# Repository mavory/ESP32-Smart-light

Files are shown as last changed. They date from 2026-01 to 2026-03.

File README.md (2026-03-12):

# ESP32 Smart Light

A system that is powered by ESP32 and controls 2 LED strips and a neopixel ring using clapping and the web!



## Why did I do this?

I wanted to create a system that could be controlled using my new Big sound module, so I started thinking and came up with this interesting idea!

## Features

- Web interface
- It has a buzzer and an RGB LED for notification
- You can clap to turn the lights on/off
- You have a neopixel ring that you can set up to 10+ mods on

## Scripts

In total, the script has about 650 lines, but the website, functions,... It´s only in this script. So just upload it via Arduino IDE to ESP32 and everything should work!!

### Home page:


## How it works?

- **Clap control:** 1x clap toggles the LED strip!! 2x claps toggle the ring and 3x claps change the ring mode
- **Physical button:** 1x click toggles the LED strip, 2x click changes brightness (strip), 3x click swaps ring modes. Long press turns the system On/Off
- **Web UI:** Change 12 ring modes (Matrix, Fire, Rainbow, etc.), 3 strip effects, and brightness
- **Status LED:** Shows WiFi status and gives color feedback (Green/Red/Blue) when you change settings
- **Auto Demo:** Randomly cycles through all ring effects every 10 seconds....

### Libraries:

```
- Adafruit_NeoPixel.h
- OneButton.h
- WiFi.h
- WebServer.h
- Preferences.h
```

## 3D models

https://www.tinkercad.com/things/eFkPVTd0Ne4-lamp?sharecode=UNrX2Xw5hONzTC9dqX5OnXKPG04cPSQhPtq6QzThrkk

Here is a view of the top and bottom of the case:

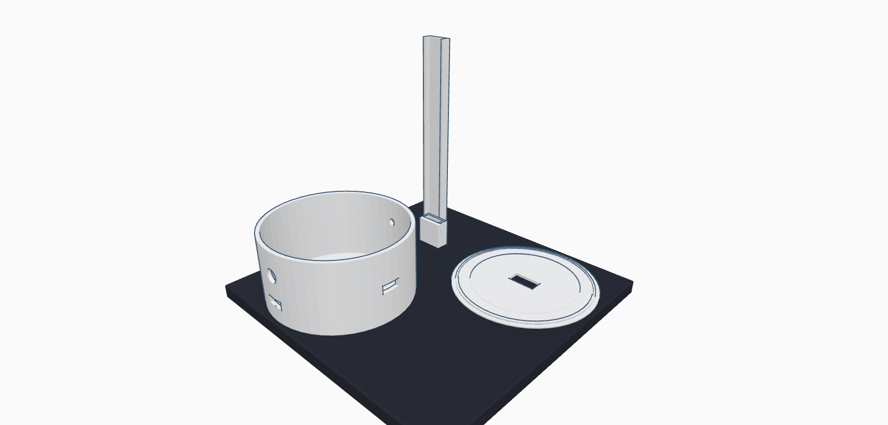
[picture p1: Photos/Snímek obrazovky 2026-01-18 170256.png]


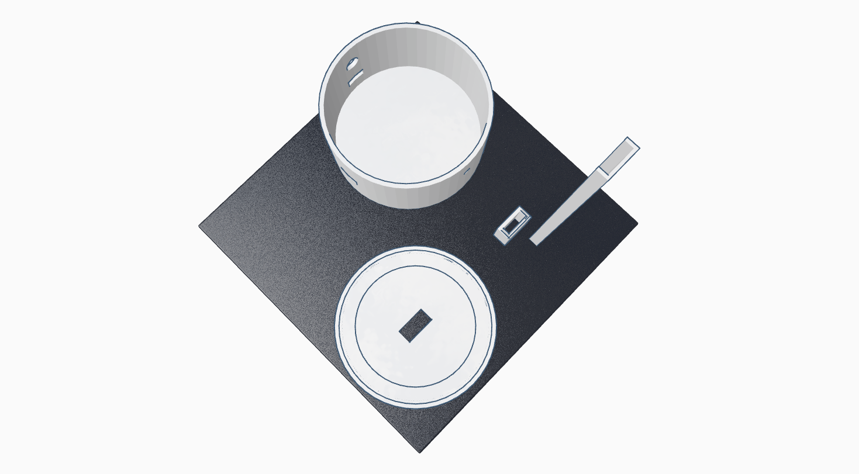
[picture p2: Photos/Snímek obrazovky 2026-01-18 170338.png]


## Wiring Diagram



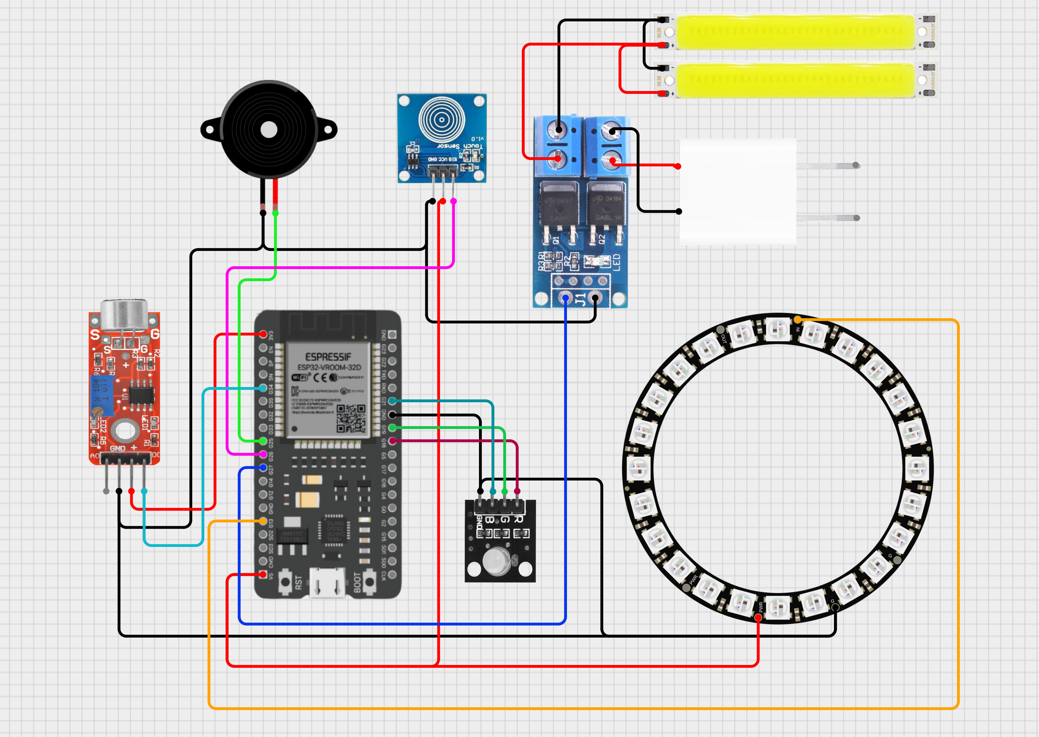
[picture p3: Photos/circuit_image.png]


## There is the final video of how it works!

_Here is a youtube video where you can see how it works:_ [Link](https://youtu.be/ElwXBvMZj_E)

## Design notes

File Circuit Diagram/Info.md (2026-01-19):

Documentation for the Smart light Control System!!

## Wiring

### LED Strip (MOSFET)
- Gate: GPIO 27
- VCC: 5V (External)
- GND: GND

### NeoPixel Ring (24 LEDs)
- Data In: GPIO 13
- VCC: 5V
- GND: GND

### Sound Sensor (Microphone)
- Digital Out: GPIO 34
- VCC: 3.3V/5V
- GND: GND

### Main Button
- Pin: GPIO 26
- GND: GND

### Buzzer
- Pin: GPIO 25
- GND: GND

### RGB Status LED (Common Cathode)
- Red: GPIO 18
- Green: GPIO 19
- Blue: GPIO 21
- Cathode: GND

---

## Technical Notes
- **Power:** The LED strip requires an external 5V power supply.

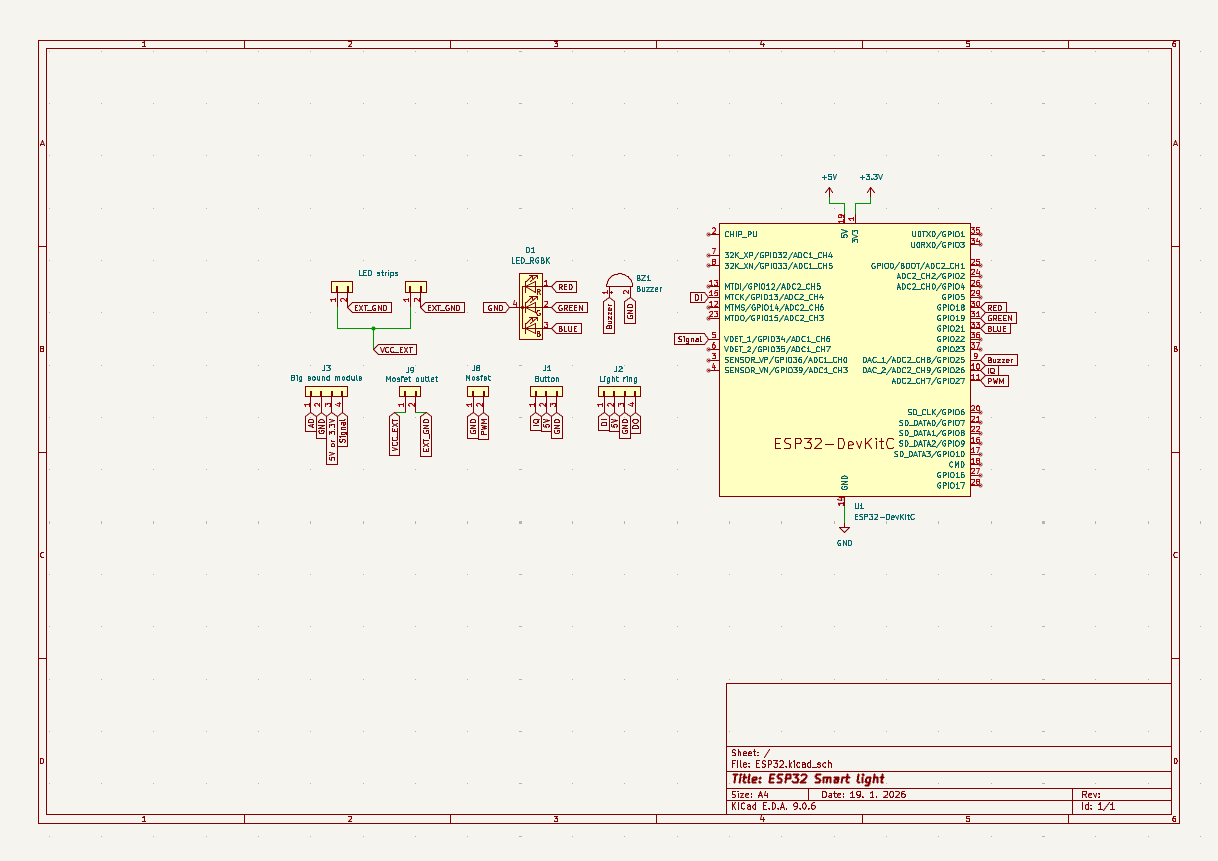
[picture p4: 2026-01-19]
Photos/Snímek obrazovky 2026-01-19 185331.png

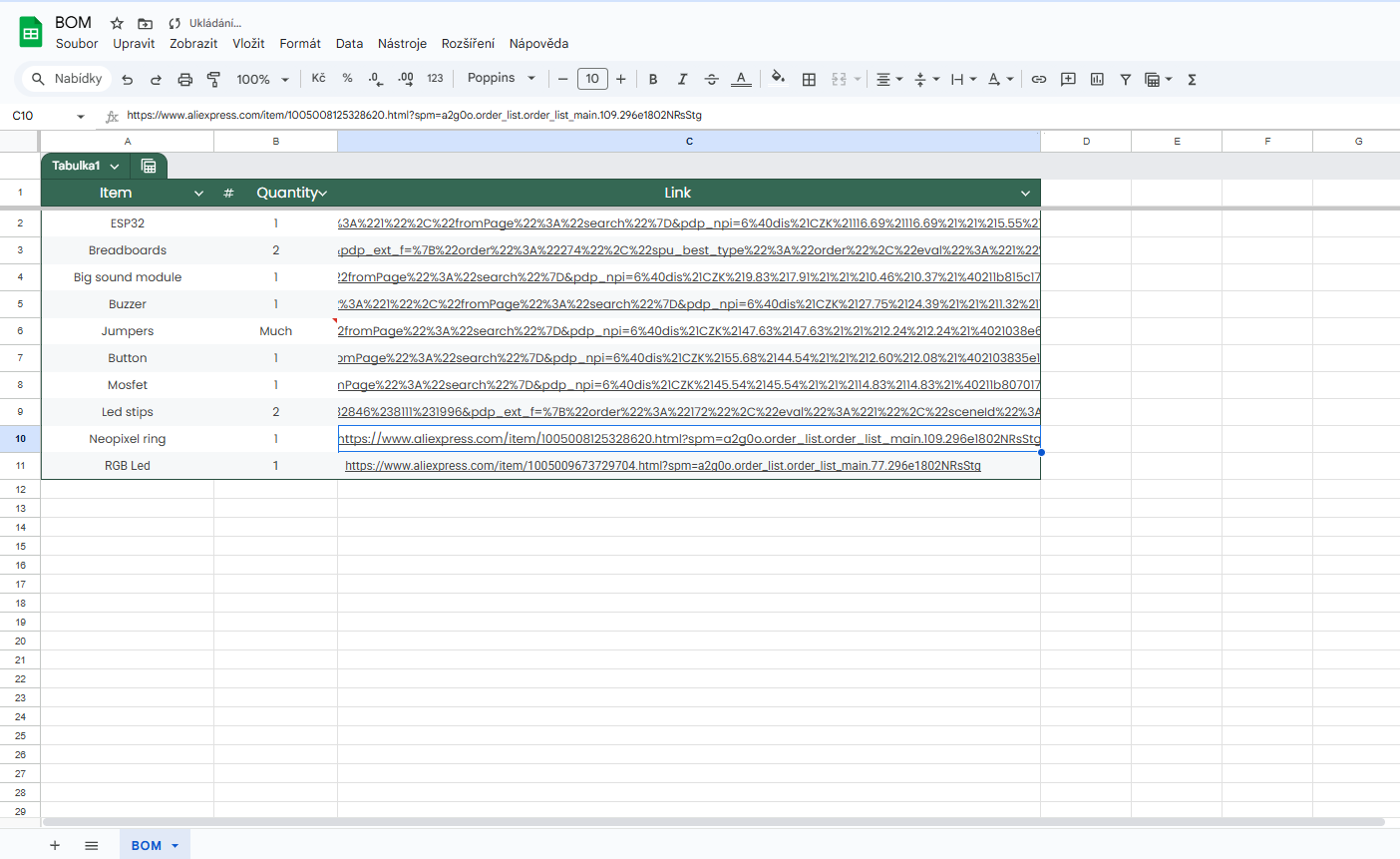
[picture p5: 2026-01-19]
Photos/Snímek obrazovky 2026-01-19 191405.png

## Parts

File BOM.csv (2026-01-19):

Item | Quantity | Link
ESP32 | 1 | https://www.aliexpress.com/item/1005009694232832.html?curPageLogUid=bPYYmnweQOZ8
Breadboards | 2 | https://www.aliexpress.com/item/1005007493250982.html?scm_id=1007.40050.354490.0&scm-url=1007.40050.354490.0
Big sound module | 1 | https://www.aliexpress.com/item/1005009123651703.html?curPageLogUid=UiuB2XQiP4lX
Buzzer | 1 | https://www.aliexpress.com/item/1005006260328559.html?curPageLogUid=u9zf8d5xh8uM
Jumpers | Much | https://www.aliexpress.com/item/1005002611994443.html?curPageLogUid=fx2zB0EGcu5H
Button | 1 | https://www.aliexpress.com/item/1005007197228321.html?curPageLogUid=niWf4yREvIVl
Mosfet | 1 | https://www.aliexpress.com/item/1005008593846004.html?curPageLogUid=lKbC2NYKhWH8
Led stips | 2 | https://www.aliexpress.com/item/4000121451290.html?scm_id=1007.40050.354490.0&scm-url=1007.40050.354490.0
Neopixel ring | 1 | https://www.aliexpress.com/item/1005008125328620.html
RGB Led | 1 | https://www.aliexpress.com/item/1005009673729704.html

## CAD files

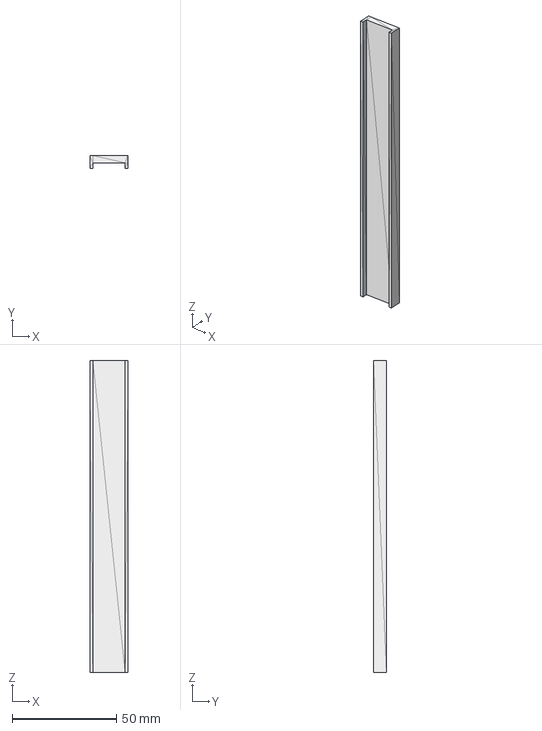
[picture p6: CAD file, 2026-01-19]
CAD/Accessories/Holder.step
18.5 x 6.20 x 150.0 mm

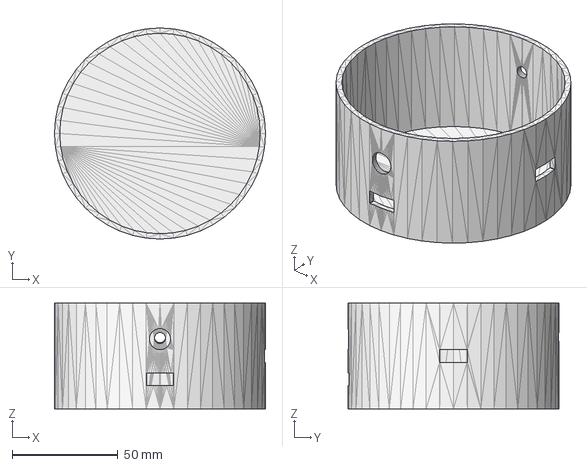
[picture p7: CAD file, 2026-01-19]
CAD/Main/Base.step
100.0 x 100.0 x 50.0 mm

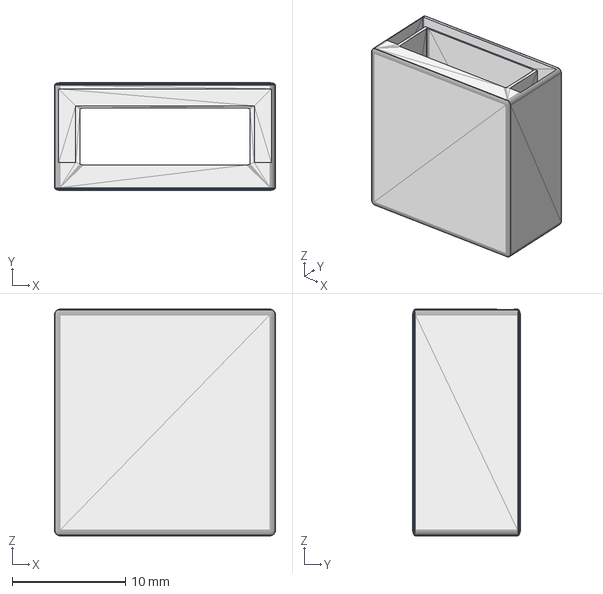
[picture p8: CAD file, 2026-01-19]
CAD/Accessories/Holder coupling.step
19.5 x 9.50 x 20.0 mm

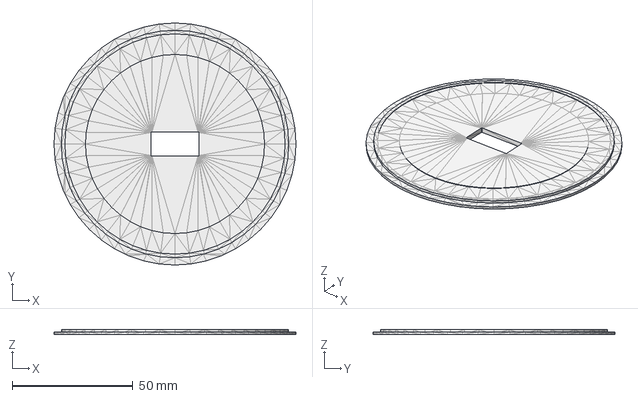
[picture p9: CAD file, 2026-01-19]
CAD/Main/Top part.step
100.0 x 100.0 x 2.00 mm

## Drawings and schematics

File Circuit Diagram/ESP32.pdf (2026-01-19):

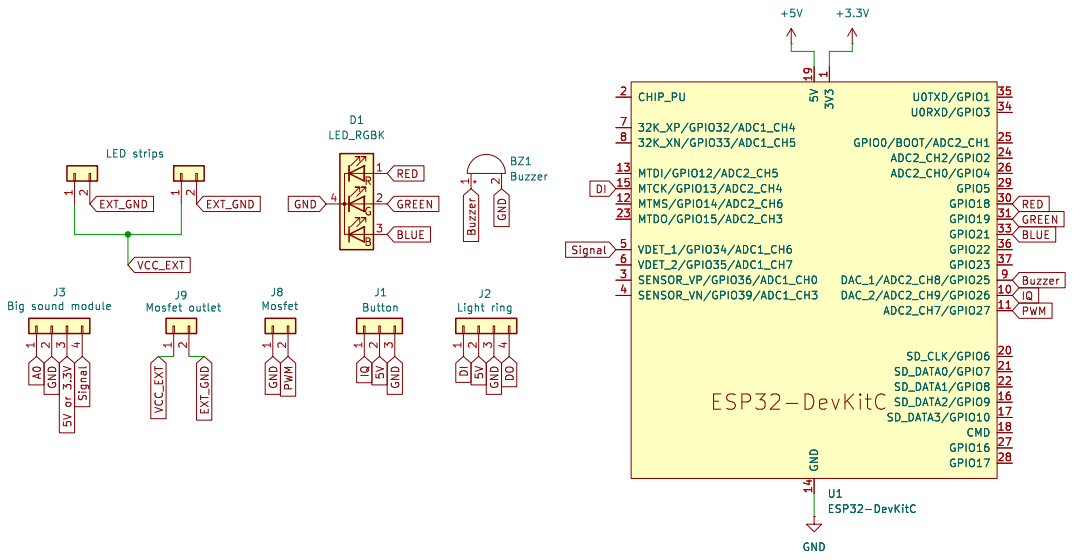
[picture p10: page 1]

Id: 1/1 Title: ESP32 Smart light File: ESP32.kicad_sch Sheet: /

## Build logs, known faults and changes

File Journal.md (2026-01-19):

<!--
  This journal is auto generated by Hack Club Blueprint.
-->

## 1/18/2026 11:26 AM - The beginning of my project!!  

_Time spent: 1.3h_  

I wanted to create **a system** that would be controllable via my **new components** and I managed to come up with a lamp that is **controllable via an end switch** and also **via a big sound microphone**.

_Here’s the breakdown of the setup:_

- ESP32 as the brain of everythinggg
- External LED Strip powered by a 400W MOSFET, which allows me to do smooth "fade-in" and "fade-out" effects and change the brightness...
- Big Sound Module (Microphone) = 2 claps toggle the main light, and 3 claps control the Ring.
- 24-LED Neopixel Ring with 10 different color modes.
- RGB LED (it glows green when turning on and flashes red when turning off).
- Passive Buzzer for feedback, so I know exactly when a command is registered.
- Micro-switch (End-stop) for "offline" control. I'm using the OneButton library so I can click once for on/off, twice for brightness, three times for Neopixel colors, or just hold it for 3 seconds to kill the ring light.


## 1/18/2026 11:49 AM - Component testing  

_Time spent: 0.9h_  

When I had the **idea ready**, I started testing all the components one by one.
First I started with the **big sound module** because I had to **adjust the sensitivity** and it took me quite a while because it seemed to be set to the _absolute maximum_, so it didn't pick up anything... I had to turn it to the **left many times** so that only one LED on the module was lit **and then it worked**!
Then I just tested if everything worked to make sure **everything** worked!


## 1/18/2026 5:41 PM - Connecting components to small breadboards  

_Time spent: 0.8h_  

After **testing** everything I decided to start connecting everything to the breadboard. I didn't want to use the huge one, so I decided to use these **2 small ones and connect them**. 
At first I didn't know how the **pins** were connected and I found out that they were in rows...
First **I had a problem** that I couldn't fit all the things on **GND**, so I thought about how to connect it. I took a jumper and connected it to the next row - _problem solved_.


## 1/18/2026 5:48 PM - Soldering!!  

_Time spent: 1.5h_  

After successfully connecting the **components**, I moved on to **soldering** the cables and soldering the **mosfet**!
At first I was wondering how to connect the mosfet, but later I found **documentation** that explained nicely how to connect **GND** and **PWM**...

## Soldering cables:
I cut the cables and then removed the protection. I tinned the cables on all sides and later I was done.


## Soldering the mosfet:
When I had the cables ready, I moved on to the aforementioned mosfet, but I was wondering what cables to use for the connection... I decided to use standard jumpers, but without headers.


## 1/18/2026 5:52 PM - Testing component connections  

_Time spent: 0.7h_  

When I finished soldering, I started **testing** the mosfet and neopixel ring.
At first, the ring didn't work because I didn't connect it properly to the **GND** common, but I fixed that mistake. The **LED** **strip** worked beautifully and for the first time in my life it even dimmed!


## 1/18/2026 6:01 PM - Component measurement  

_Time spent: 0.9h_  

Before coding, I started **modeling**.
As I always **say**, _TinkerCad_ is the easiest and easiest to learn for me, so I chose this **program** again, but before I **started**, I had to measure all the **components** to make sure they fit and add small **deviations** to them.


## 1/18/2026 6:22 PM - The beginning of 3D modeling  

_Time spent: 2.2h_  

After measuring and writing down all the sizes, I moved to **TinkerCad**. I created a new project and started **creating**.
I thought about what shape I would make and decided on a **circle** because I could easily insert the **neopixel** **ring** there and everything would fit **nicely**.
I took a piece of paper with the sizes and started calculating how big I would make it... I **decided** that the total circle would be **90x90mm** and then I continued with the hole.
Later I also started making the top **lid**, into which the mined ring will be **inserted**:
Snímek obrazovky 2026-01-18 155757

## 1/18/2026 6:25 PM - Measurement error!  

_Time spent: 0.5h_  

When I was checking how to make a large hole for the **neopixel** ring, I also looked at the website of the **store** where I bought it and they wrote **completely different** things there... So I decided that I would continue with my **sizes** anyway, but I would adjust the case to **100x100mm**, and if everything would **fit** there.
Snímek obrazovky 2026-01-18 164253

## 1/18/2026 6:37 PM - Finishing the top and bottom of the 3D case  

_Time spent: 1.2h_  

After a short break I started making the **3D case** again...
I didn't know exactly how I was going to make the **top** part, but I decided to make a hole at the top for adding **LED strips** later. It took me a while and I think it will need some more **work** anyway... The **hardest part** was probably finding the right place for the **neopixel ring**.


## 1/18/2026 6:46 PM - Groove for LED strip  

_Time spent: 0.6h_  

Once I had the **3D case** finished, I started working on the **groove** for the led strip.
First I had to create a bracket that would **connect** to the 3D case and the groove would be inserted into it.
I was thinking about what **design** to choose and decided on a regular "**U**" style where the strip would be **glued**.


## 1/19/2026 9:24 AM - Removing supports and strange things  

_Time spent: 0.5h_  

After **printing** the bottom part I started removing the supports. I also had to take a **knife** and cut off the little **bumps** it made near the **holes**...
Once I had it, I took some **sandpaper** and started sanding the **case** to make it look a bit nicer.


## 1/19/2026 9:35 AM - Inserting components into the case!!  

_Time spent: 0.9h_  

After successfully modifying the case, I started putting the **breadboard** and components into the case. I had a few **problems** that occurred to me:
- I turned the **breadboard** the wrong way around, so I had to take it **all** out and put it back in, because only one side has a hole for the button, which is placed from the **side**... 💀
- I took out the **components** a few times to put the cables under them, so that **everything** would fit nicely into the case
- I also had to **disconnect** the mosfet and thread the **cable** through the hole so that the **LED** strips could be powered.

_Otherwise, I did the case and things like that well, because the cables fit perfectly in there._


## 1/19/2026 9:46 AM - Top printing  

_Time spent: 1.4h_  

In my free time I started **printing** the upper part of the **3D case**. Then I took it, modified it again with a **knife**, **sandpaper** and removed the **supports** where I did research for a good removal of the supports and it worked! Anyway, here is an example:
Snímek obrazovky 2026-01-19 094125
Snímek obrazovky 2026-01-19 094150
I took some quick-drying glue and some **isopropyl alcohol**, which I used to clean **everything** so that there was **no** **grease** and it would stick well...
I applied a small amount of **glue** to the neopixel ring and stuck it into the **hole** for the neopixel just **mentioned**.


## 1/19/2026 10:06 AM - Thickness error  

_Time spent: 0.6h_  

I thought it would work fine, but here came a **small problem**...
When I tried the **strips** and turned them on on the 3D holder, the light was **shining** through from one side where it shouldn't.
So I went back into the **program** and reworked it to be thicker and not let in light. I also **adjusted** the fill to **100% in BambuLab** studio and added **3 wall perimeters**.
20260119_094715 (1)

## 1/19/2026 10:27 AM - Remodeling :(  

_Time spent: 0.8h_  

When I got the new **piece** printed, I was amazed at how it **still** let in light even though I had enlarged the wall by about **50%**...
So I went **back** into the program and added a few more **millimeters** and hopefully it will be good. Next, I put on the holder for the **LED strips** and it works very well so far!


## 1/19/2026 10:33 AM - Start of coding  

_Time spent: 1.4h_  

In the **meantime**, I decided to start making a **code**. Before that, it was just a test code to see if everything works, and now we're going to the **master** **code**!
At first, I didn't know how to **code** it, but gradually I started thinking of **various** other things to **improve** it...
So far, the code can only turn the **led strip** on and off (1x) and clap twice to turn the **ring** on/off.


## 1/19/2026 11:46 AM - Continuing coding!!  

_Time spent: 1.1h_  

I continued coding and **decided** that I would like to add some mods for the **ring** and also to dim the led strip.
I achieved this by adding a **OneButton** function to the code, which was there **before**, but I didn't use it that **much**.
I also added the ability to **clap** multiple times and here's what it means:
- **1x** = _turns the led strips on/off_
- **2x** = _turns the neopixel ring on/off_
- **3x** = _changes the sew mode of the neopixel ring_


## 1/19/2026 11:57 AM - Gluing the upper part of the holder  

_Time spent: 0.7h_  

When I had some time, I started **gluing** the first part of the **strip** holder.
I thought it would be **easy**, but it wasn't **possible** at all... At first, I just applied **glue** to the holder and tried to let it **dry** - but it didn't work. I had to take a **stronger** **glue** and started adding from both **sides**. It was better, but it still **wasn't enough** (_it was falling to the sides, etc_).
So I put a **big dose of glue** on top and held it for about **20 minutes**, then I turned it over and started adding glue from the other **side** again and it helped! We just **applied** glue a few times, maybe it held even more, but now **I'm** **satisfied**.
20260119_114646 (1)

## 1/19/2026 12 PM - The 3D case is ready!!!  

_Time spent: 1.3h_  

After a long time I finished the **3D case** and glued **everything**.
At first the holders for the **LED strips** didn't hold together, so I had to **sand** them down first and then try to **glue** them...

I guess the most difficult thing was to somehow straighten it out and do it **right**, because before I always had it either too far **forward** or too far **back**. So now it's level, but I still have to **sand** it a little to fine-tune the **straightness**.


## 1/19/2026 4:48 PM - Creating a website for the system  

_Time spent: 1.2h_  

I decided that I would like to use one more cool feature of **ESP32** - **WiFi**!
So I thought about how to create a **website**, but so that it works... At first I thought that I could put **buttons** and **sliders** on the website, that was just the **beginning**, but unfortunately when I created the **page**, the system did not work, so later I had to start again and with a **better** **look**!
Snímek obrazovky 2026-01-19 160110

## 1/19/2026 4:55 PM - Continuing to create the website  

_Time spent: 1.6h_  

When I had a finished but **non-functional** website, I decided to completely **redo** it.
I deleted the **code** and started from scratch... I was thinking about what look to use and **decided** to use white and blue with a touch of minimalism!
I gradually added **buttons**, **sliders**, **selections**,.... until I came to a functional **website** that could **control** my system - But it had one flaw:
- When I wanted to turn something **off**/**on** via the button and then turn it **on**/**off** via the website, the website threw me nonsense and **nothing** worked...

### I was missing something there...
Snímek obrazovky 2026-01-19 155724

## 1/19/2026 5:17 PM - Website completion!  

_Time spent: 1.4h_  

After a **few hours** I finished the website!
It took me a long time to get it up and **running**, but I managed to do it... I had to **rework** the logic of the operation. First I thought about adding a "_Demo Mode_" that would constantly **cycle** through all the modes, and I **managed** to do that!
I also fixed the **buttons** and added "_live fetch_" which works as follows:
- I press, for example, a button on the case that turns on the light and on the website the button status also changes to on.

This was probably the **most** **difficult** **part** of the editing, because I was mostly editing and **looking** for errors that were there.
Snímek obrazovky 2026-01-19 163954

## 1/19/2026 5:21 PM - Language editing  

_Time spent: 0.5h_  

To make the page readable for **everyone**, I had to edit the code one last time by **rewriting** the main logic into **English**. It only took me about half an hour and I'm happy for it!


## 1/19/2026 6:00 PM - Finishing the case  

_Time spent: 0.7h_  

As **I** **wrote** before, I still had to finish the case to make it **perfect**. I added a little glue at one point because the **top** **part** was peeling off a little, but that's it.
I also took some finer grit **sandpaper** and sanded the case a little in some **places** because there were still some **glue** residue, some **bumps**, etc.


## 1/19/2026 6:52 PM - Circuit diagram in KiCad  

_Time spent: 0.9h_  

After finishing the **3D case**, I moved on to the schematic, which I always do in **KiCad**. At first, I was thinking about what pins I would use mainly for the **mosfet**, but I decided to use normal...
I then gradually inserted **all** the components and also prepared the connection **symbols**.


## 1/19/2026 6:57 PM - Circuit diagram is finished!!  

_Time spent: 1.5h_  

When I added the **symbols**, I started connecting the components with the **ESP32**. The microphone took me the most time because I forgot to **connect it**, so I had to find it on the internet (_the 3D case was already closed_).
So I finished the last part, rotated a few symbols and renamed the **project**.


## 1/19/2026 7 PM - Preparing things for the GitHub repo  

_Time spent: 0.6h_  

When I was slowly **finishing** my project, I started making **BOM** and preparing things for export to **GitHub**.
I tried to find the cheapest things with cheap shipping and I also had to **convert** my 3D models from **.STL** to **.STEP** via convector.
I also exported the file for ESP32 and prepared everything in a **folder** for upload!!


## 1/19/2026 8 PM - GitHub editing  

_Time spent: 0.8h_  

After exporting I started uploading **files** to the repo and also started writing **README****.md** which is very **important**. I also had to make a journal file where **everything** is described.
Next I made a video of how it works and uploaded it to **YouTube**...


## 1/19/2026 9 PM - ESP32 Smart Light it is finished!!!  

_Time spent: 1.3h_  

A system that is powered by **ESP32** and controls 2 LED **strips** and a neopixel ring using clapping and the **web**!


## Why did I do this?

I wanted to create a **system** that could be controlled using my new **Big sound module**, so I started thinking and came up with this interesting **idea**!

## Features

- Web interface
- It has a buzzer and an RGB LED for notification
- You can clap to turn the lights on/off
- You have a neopixel ring that you can set up to 10+ mods on

## Scripts

In total, the script has about **650 lines**, but the website, functions,...It´s only in this **script**. So just upload it via **Arduino IDE** to ESP32 and everything should work!!

### Home page:
Snímek obrazovky 2026-01-19 213811

## How it works?

- **Clap control:** 1x clap toggles the LED strip!! 2x claps toggle the ring and 3x claps change the ring mode
- **Physical button:** 1x click toggles the LED strip, 2x click changes brightness (strip), 3x click swaps ring modes. Long press turns the system On/Off
- **Web UI:** Change 12 ring modes (Matrix, Fire, Rainbow, etc.), 3 strip effects, and brightness
- **Status LED:** Shows WiFi status and gives color feedback (Green/Red/Blue) when you change settings
- **Auto Demo:** Randomly cycles through all ring effects every 10 seconds....

### Libraries:

```
- Adafruit_NeoPixel.h
- OneButton.h
- WiFi.h
- WebServer.h
- Preferences.h
```

## 3D models

Here is a view of the top and bottom of the case:
Snímek obrazovky 2026-01-18 170256
Snímek obrazovky 2026-01-18 170338

## Wiring Diagram



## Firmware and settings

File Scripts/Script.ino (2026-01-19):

#include <Adafruit_NeoPixel.h>
#include <OneButton.h>
#include <WiFi.h>
#include <WebServer.h>
#include <Preferences.h> 

// WiFi!
const char* ST_SSID     = "wifi";
const char* ST_PASSWORD = "pass";

WebServer server(80);
Preferences preferences; // Storage instance

// PINOUT!!
#define PIN_SOUND    34
#define PIN_MOSFET   27
#define PIN_BUTTON   26
#define PIN_BUZZER   25
#define PIN_NEOPIXEL 13

#define RGB_R 18
#define RGB_G 19
#define RGB_B 21

#define NUM_LEDS 24

// ledcsssssss
#define CH_MOSFET  0
#define CH_BUZZER  1
#define CH_R       2
#define CH_G       3
#define CH_B       4

Adafruit_NeoPixel ring(NUM_LEDS, PIN_NEOPIXEL, NEO_GRB + NEO_KHZ800);
OneButton button(PIN_BUTTON, true);

// variability
bool systemOn = true;
bool stripOn  = false;
bool ringOn   = true;
bool buzzerOn = true;
bool statusLedOn = true;
bool autoDemo = false; 

// LED Strip
int stripBrightness = 255;
int stripEffect = 0;
int stripCurrentPWM = 0;
unsigned long stripEffectTimer = 0;
int breathVal = 0;
bool breathDir = true;

// NeoPixel Ring
int neoBrightness = 100;
int neoMode = 0;
const int NEO_MODES_COUNT = 12; 
unsigned long neoTimer = 0;
uint16_t neoStep = 0;
unsigned long demoTimer = 0;

// Clap clap clap clap
unsigned long clapWindowStart = 0;
unsigned long lastClapTime = 0;
int clapCount = 0;
unsigned long ignoreMicUntil = 0;
const unsigned long CLAP_WINDOW = 700;
const unsigned long CLAP_DEBOUNCE = 120;

// Audio & Feedback
unsigned long beepEnd = 0;
bool beeping = false;

// RGB Status 
unsigned long feedbackTimer = 0;
uint8_t fbR=0, fbG=0, fbB=0; 

// HTML web kod
const char index_html[] PROGMEM = R"rawliteral(
<!DOCTYPE html>
<html lang="en">
<head>
  <meta charset="UTF-8">
  <meta name="viewport" content="width=device-width, initial-scale=1.0, user-scalable=no">
  <title>Smart Room</title>
  <style>
    :root { --primary: #007bff; --bg: #f0f2f5; --card: #ffffff; --text: #333; }
    body { font-family: -apple-system, BlinkMacSystemFont, "Segoe UI", Roboto, Helvetica, Arial, sans-serif; background-color: var(--bg); color: var(--text); margin: 0; padding: 10px; text-align: center; }
    .container { max-width: 500px; margin: 0 auto; padding-bottom: 50px; }
    
    h1 { color: var(--primary); font-weight: 200; letter-spacing: 1px; margin: 20px 0; }
    
    .card { background: var(--card); padding: 20px; border-radius: 20px; box-shadow: 0 8px 30px rgba(0,0,0,0.08); margin-bottom: 15px; transition: transform 0.2s; }
    .card:active { transform: scale(0.98); }
    .card h2 { margin: 0 0 15px 0; font-size: 1.1rem; color: #888; text-transform: uppercase; letter-spacing: 1px; border-bottom: 1px solid #eee; padding-bottom: 10px; text-align: left;}
    
    .row { display: flex; justify-content: space-between; align-items: center; margin-bottom: 12px; }
    .label { font-weight: 500; font-size: 1rem; }
    
    /* IOS Style Switch */
    .switch { position: relative; display: inline-block; width: 50px; height: 28px; }
    .switch input { opacity: 0; width: 0; height: 0; }
    .slider { position: absolute; cursor: pointer; top: 0; left: 0; right: 0; bottom: 0; background-color: #e4e4e4; transition: .3s; border-radius: 34px; }
    .slider:before { position: absolute; content: ""; height: 22px; width: 22px; left: 3px; bottom: 3px; background-color: white; transition: .3s; border-radius: 50%; box-shadow: 0 2px 5px rgba(0,0,0,0.2); }
    input:checked + .slider { background-color: var(--primary); }
    input:checked + .slider:before { transform: translateX(22px); }
    
    /* Inputs */
    input[type=range] { width: 100%; -webkit-appearance: none; height: 6px; border-radius: 5px; background: #ddd; outline: none; margin-top: 10px; }
    input[type=range]::-webkit-slider-thumb { -webkit-appearance: none; width: 22px; height: 22px; border-radius: 50%; background: var(--primary); cursor: pointer; box-shadow: 0 2px 6px rgba(0,123,255,0.4); }
    
    select { width: 100%; padding: 12px; border-radius: 12px; border: 1px solid #eee; background: #f9f9f9; font-size: 1rem; color: #333; outline: none; -webkit-appearance: none; }
    
    .status-badge { display: inline-block; padding: 4px 8px; border-radius: 4px; font-size: 0.7rem; color: white; background: #ccc; }
    .status-badge.conn { background: #28a745; }
    
    /* Demo Button */
    .demo-btn { background: linear-gradient(45deg, #ff9a9e 0%, #fad0c4 99%, #fad0c4 100%); border: none; padding: 10px 20px; color: white; border-radius: 50px; font-weight: bold; cursor: pointer; width: 100%; }
    .demo-btn.active { background: linear-gradient(45deg, #a18cd1 0%, #fbc2eb 100%); }

  </style>
</head>
<body>
  <div class="container">
    <h1>SMART ROOM <span id="connInd" class="status-badge">...</span></h1>

    <div class="card" style="border-left: 5px solid var(--primary);">
      <div class="row">
        <span class="label">MASTER SWITCH</span>
        <label class="switch"><input type="checkbox" id="sysSw" onchange="send('sys', this.checked)"><span class="slider"></span></label>
      </div>
    </div>

    <div class="card">
      <h2>Ring Light</h2>
      <div class="row">
        <span class="label">Status</span>
        <label class="switch"><input type="checkbox" id="ringSw" onchange="send('ring', this.checked)"><span class="slider"></span></label>
      </div>
      <div class="row">
        <select id="ringMode" onchange="sendVal('neoMode', this.value)">
          <option value="0">Orange (Relax)</option>
          <option value="1">Blue Radar</option>
          <option value="2">Rainbow (Flow)</option>
          <option value="3">Sparkle</option>
          <option value="4">Warning (Red Wipe)</option>
          <option value="5">Theater</option>
          <option value="6">Breathe (Purple)</option>
          <option value="7">Police</option>
          <option value="8">Matrix (Green)</option>
          <option value="9">Fire</option>
          <option value="10">Comet</option>
          <option value="11">Disco Random</option>
        </select>
      </div>
      <input type="range" id="ringBri" min="0" max="255" onchange="sendVal('neoBri', this.value)">
    </div>

    <div class="card">
      <h2>LED Strip</h2>
      <div class="row">
        <span class="label">Status</span>
        <label class="switch"><input type="checkbox" id="stripSw" onchange="send('strip', this.checked)"><span class="slider"></span></label>
      </div>
      <div class="row">
        <select id="stripEff" onchange="sendVal('stripEff', this.value)">
          <option value="0">Static light</option>
          <option value="1">Breathing (Fade)</option>
          <option value="2">Strobe</option>
        </select>
      </div>
      <input type="range" id="stripBri" min="0" max="255" onchange="sendVal('stripBri', this.value)">
    </div>

    <div class="card">
      <h2>Features</h2>
      <div class="row">
        <span class="label">Button beeps</span>
        <label class="switch"><input type="checkbox" id="buzSw" onchange="send('buz', this.checked)"><span class="slider"></span></label>
      </div>
      <div class="row">
        <span class="label">Status LED</span>
        <label class="switch"><input type="checkbox" id="rgbSw" onchange="send('rgb', this.checked)"><span class="slider"></span></label>
      </div>
      <div class="row" style="margin-top:15px;">
        <button id="demoBtn" class="demo-btn" onclick="toggleDemo()">AUTO DEMO MODE</button>
      </div>
    </div>
  </div>

<script>
  let isDragging = false;
  
  // Prevents slider updates while dragging
  document.querySelectorAll('input[type=range]').forEach(el => {
    el.addEventListener('mousedown', () => isDragging = true);
    el.addEventListener('mouseup', () => isDragging = false);
    el.addEventListener('touchstart', () => isDragging = true);
    el.addEventListener('touchend', () => isDragging = false);
  });

  function send(target, state) {
    fetch('/set?target=' + target + '&state=' + (state ? '1' : '0'));
  }
  
  function sendVal(target, val) {
    fetch('/set?target=' + target + '&val=' + val);
  }

  function toggleDemo() {
    fetch('/set?target=demo&state=toggle');
  }

  // Main AJAX loop - runs every 500ms
  function updateStatus() {
    fetch('/status')
      .then(response => response.json())
      .then(data => {
        document.getElementById('connInd').className = 'status-badge conn';
        document.getElementById('connInd').innerText = 'ONLINE';

        // Update switches only if user is not interacting
        if (document.activeElement.type !== 'checkbox') {
           document.getElementById('sysSw').checked = data.sys;
           document.getElementById('ringSw').checked = data.ring;
           document.getElementById('stripSw').checked = data.strip;
           document.getElementById('buzSw').checked = data.buz;
           document.getElementById('rgbSw').checked = data.rgb;
        }

        // Update sliders only when not dragging
        if (!isDragging) {
          document.getElementById('ringBri').value = data.nBri;
          document.getElementById('stripBri').value = data.sBri;
        }

        // Selects
        if (document.activeElement.tagName !== 'SELECT') {
           document.getElementById('ringMode').value = data.nMode;
           document.getElementById('stripEff').value = data.sEff;
        }

        // Demo button 
        const dBtn = document.getElementById('demoBtn');
        if (data.demo) {
          dBtn.classList.add('active');
          dBtn.innerText = "DEMO RUNNING...";
        } else {
          dBtn.classList.remove('active');
          dBtn.innerText = "AUTO DEMO MODE";
        }
      })
      .catch(() => {
        document.getElementById('connInd').className = 'status-badge';
        document.getElementById('connInd').innerText = 'OFFLINE';
      });
  }

  setInterval(updateStatus, 500); // Fast update
  window.onload = updateStatus;
</script>
</body>
</html>
)rawliteral";

// rgb dioda
void hwRGB(uint8_t r, uint8_t g, uint8_t b) {
  ledcWrite(CH_R, r);
  ledcWrite(CH_G, g);
  ledcWrite(CH_B, b);
}

// zase rgb dioda
void handleStatusLed() {
  // dark (cerna)
  if (!statusLedOn) {
    hwRGB(0, 0, 0);
    return;
  }

  // 2. feedback
  if (millis() < feedbackTimer) {
    hwRGB(fbR, fbG, fbB);
    return;
  }

  // 3. WiFi
  if (WiFi.status() != WL_CONNECTED) {
    // Blinking blue
    bool blink = (millis() / 500) % 2;
    hwRGB(0, 0, blink ? 255 : 0);
    return;
  }

  // 4. Normal 
  if (systemOn) {
    // Power On 
    hwRGB(0, 5, 0); 
  } else {
    // Power Off 
    hwRGB(5, 0, 0);
  }
}

void triggerFeedback(uint8_t r, uint8_t g, uint8_t b) {
  fbR = r; fbG = g; fbB = b;
  feedbackTimer = millis() + 200; // 200 milise-"kund"
}

// audio 
void beep(int freq, int dur) {
  if (!buzzerOn || !systemOn) return;
  ledcWriteTone(CH_BUZZER, freq);
  beepEnd = millis() + dur;
  beeping = true;
  ignoreMicUntil = beepEnd + 250;
}

void handleBeep() {
  if (beeping && millis() > beepEnd) {
    ledcWriteTone(CH_BUZZER, 0);
    beeping = false;
  }
}

// saving 
void saveSettings() {
  preferences.putBool("sys", systemOn);
  preferences.putBool("ring", ringOn);
  preferences.putBool("strip", stripOn);
  preferences.putInt("nMode", neoMode);
  preferences.putInt("nBri", neoBrightness);
  preferences.putInt("sBri", stripBrightness);
}

// tlačítko
void btnClick() {
  if(!systemOn) return;
  stripOn = !stripOn;
  triggerFeedback(stripOn ? 0 : 255, stripOn ? 255 : 0, 0);
  beep(1000, 70);
  saveSettings();
}

void btnDouble() {
  if(!systemOn) return;
  stripBrightness = (stripBrightness >= 200) ? 50 : stripBrightness + 50;
  triggerFeedback(0, 0, 255); // Blue
  beep(1200, 60);
  saveSettings();
}

void btnTriple() {
  if(!systemOn) return;
  neoMode = (neoMode + 1) % NEO_MODES_COUNT;
  triggerFeedback(150, 0, 150); // Purple
  beep(1400, 60);
  saveSettings();
}

void btnLong() {
  systemOn = !systemOn;
  triggerFeedback(255, 255, 0); // Yellow
  if(systemOn) beep(2000, 100);
  else {
     beep(500, 300);
     ring.clear(); ring.show();
     ledcWrite(CH_MOSFET, 0);
  }
  saveSettings();
}

// clap kontrola
void handleClap() {
  if (!systemOn || digitalRead(PIN_BUTTON) == LOW) return;

  unsigned long now = millis();
  if (digitalRead(PIN_SOUND) == HIGH && now > ignoreMicUntil) {
    if (now - lastClapTime > CLAP_DEBOUNCE) {
      lastClapTime = now;
      if (clapCount == 0) clapWindowStart = now;
      clapCount++;
    }
  }

  if (clapCount > 0 && now - clapWindowStart > CLAP_WINDOW) {
    if (clapCount == 1) btnClick();
    else if (clapCount == 2) { ringOn = !ringOn; saveSettings(); }
    else if (clapCount == 3) btnTriple();
    clapCount = 0;
  }
}

// striptérka led
void handleStrip() {
  if (!systemOn || !stripOn) {
    if (stripCurrentPWM > 0) {
      stripCurrentPWM = max(0, stripCurrentPWM - 5);
      ledcWrite(CH_MOSFET, stripCurrentPWM);
    }
    return;
  }

  int target = stripBrightness;
  
  if (stripEffect == 0) { // Static
    if (stripCurrentPWM < target) stripCurrentPWM++;
    else if (stripCurrentPWM > target) stripCurrentPWM--;
    ledcWrite(CH_MOSFET, stripCurrentPWM);
  } 
  else if (stripEffect == 1) { // Breathe
    if (millis() - stripEffectTimer > 10) {
      stripEffectTimer = millis();
      if (breathDir) {
        breathVal++; if (breathVal >= target) breathDir = false;
      } else {
        breathVal--; if (breathVal <= 10) breathDir = true;
      }
      ledcWrite(CH_MOSFET, breathVal);
      stripCurrentPWM = breathVal;
    }
  }
  else if (stripEffect == 2) { // Strobe
    if (millis() - stripEffectTimer > 100) {
      stripEffectTimer = millis();
      breathDir = !breathDir;
      ledcWrite(CH_MOSFET, breathDir ? target : 0);
    }
  }
}

// neopixel ring
uint32_t wheel(byte p) {
  p = 255 - p;
  if (p < 85) return ring.Color(255 - p * 3, 0, p * 3);
  if (p < 170) { p -= 85; return ring.Color(0, p * 3, 255 - p * 3); }
  p -= 170; return ring.Color(p * 3, 255 - p * 3, 0);
}

// low taper fade
void fadeToBlack(uint8_t amt) {
  for(int i=0; i<NUM_LEDS; i++) {
    uint32_t c = ring.getPixelColor(i);
    int r = (c >> 16) & 0xFF;
    int g = (c >> 8) & 0xFF;
    int b = c & 0xFF;

    r = (r <= 10) ? 0 : (int)r - (r * amt / 256);
    g = (g <= 10) ? 0 : (int)g - (g * amt / 256);
    b = (b <= 10) ? 0 : (int)b - (b * amt / 256);
    
    ring.setPixelColor(i, ring.Color(r, g, b));
  }
}

void updateNeo() {
  // Demo Mode 
  if (autoDemo && systemOn) {
    if (millis() - demoTimer > 10000) { //10se-"kund"
      demoTimer = millis();
      neoMode = random(0, NEO_MODES_COUNT);
      ringOn = true;
    }
  }

  if (!systemOn || !ringOn) {
    ring.clear(); ring.show(); return;
  }

  int delayTime = 40;
  if (neoMode == 2) delayTime = 20;
  if (neoMode == 7) delayTime = 80;
  if (neoMode == 9) delayTime = 60; // Fireee!!!
  if (neoMode == 11) delayTime = 200; // Disco

  if (millis() - neoTimer < delayTime) return;
  neoTimer = millis();

  ring.setBrightness(neoBrightness);

  switch (neoMode) {
    case 0: for(int i=0; i<NUM_LEDS; i++) ring.setPixelColor(i, ring.Color(255, 60, 0)); break; // Orange
    case 1: // Blue Radar
      fadeToBlack(40); 
      ring.setPixelColor(neoStep % NUM_LEDS, ring.Color(0, 100, 255));
      neoStep++;
      break;
    case 2: // Rainbow
      for(int i=0; i<NUM_LEDS; i++) ring.setPixelColor(i, wheel((i * 256 / NUM_LEDS + neoStep) & 255));
      neoStep++;
      break;
    case 3: // Sparkle
      fadeToBlack(20); 
      if(random(10) > 6) ring.setPixelColor(random(NUM_LEDS), ring.Color(255, 255, 255));
      break;
    case 4: // Red Wipe
      ring.setPixelColor(neoStep % NUM_LEDS, ring.Color(255, 0, 0));
      ring.setPixelColor((neoStep+1) % NUM_LEDS, 0);
      neoStep++;
      break;
    case 5: // Theater
      for (int i=0; i<NUM_LEDS; i++) ring.setPixelColor(i, 0);
      for (int i=0; i<NUM_LEDS; i+=3) ring.setPixelColor((i+neoStep)%NUM_LEDS, ring.Color(200, 0, 200));
      neoStep++;
      break;
    case 6: // Breathe Purple
      { float val = (exp(sin(millis()/2000.0*PI)) - 0.36787944)*108.0;
        for(int i=0; i<NUM_LEDS; i++) ring.setPixelColor(i, ring.Color((int)val, 0, (int)val)); }
      break;
    case 7: // Police
      for(int i=0; i<NUM_LEDS; i++) ring.setPixelColor(i, (neoStep%2==0) ? (i<NUM_LEDS/2 ? ring.Color(255,0,0) : 0) : (i>=NUM_LEDS/2 ? ring.Color(0,0,255) : 0));
      neoStep++;
      break;
    case 8: // Matrix Green
      fadeToBlack(30); 
      if(random(10)>5) ring.setPixelColor(random(NUM_LEDS), ring.Color(0, 255, 0));
      break;
    case 9: // Fire
      for(int i=0; i<NUM_LEDS; i++) {
        int r = random(150, 255); int g = random(0, 80);
        ring.setPixelColor(i, ring.Color(r, g, 0));
      }
      break;
    case 10: // Comet
      fadeToBlack(60); 
      ring.setPixelColor(neoStep % NUM_LEDS, ring.Color(255, 255, 255));
      neoStep++;
      break;
    case 11: // Disco Random
      for(int i=0; i<NUM_LEDS; i++) ring.setPixelColor(i, ring.Color(random(255), random(255), random(255)));
      break;
  }
  ring.show();
}

// web server
void handleRoot() { server.send(200, "text/html", index_html); }

void handleSet() {
  if (server.hasArg("target")) {
    String t = server.arg("target");
    if (server.hasArg("state")) {
      bool s = (server.arg("state") == "1");
      if (t == "sys") systemOn = s;
      else if (t == "ring") ringOn = s;
      else if (t == "strip") stripOn = s;
      else if (t == "buz") buzzerOn = s;
      else if (t == "rgb") statusLedOn = s;
      else if (t == "demo") autoDemo = !autoDemo; // demo
    }
    if (server.hasArg("val")) {
      int v = server.arg("val").toInt();
      if (t == "neoMode") { neoMode = v; neoStep = 0; ring.clear(); }
      else if (t == "neoBri") neoBrightness = v;
      else if (t == "stripBri") stripBrightness = v;
      else if (t == "stripEff") stripEffect = v;
    }
    saveSettings(); // Save 
    server.send(200, "text/plain", "OK");
  } else server.send(400, "text/plain", "ERR");
}

void handleStatus() {
  String json = "{";
  json += "\"sys\":" + String(systemOn) + ",";
  json += "\"ring\":" + String(ringOn) + ",";
  json += "\"strip\":" + String(stripOn) + ",";
  json += "\"buz\":" + String(buzzerOn) + ",";
  json += "\"rgb\":" + String(statusLedOn) + ",";
  json += "\"demo\":" + String(autoDemo) + ",";
  json += "\"nBri\":" + String(neoBrightness) + ",";
  json += "\"sBri\":" + String(stripBrightness) + ",";
  json += "\"nMode\":" + String(neoMode) + ",";
  json += "\"sEff\":" + String(stripEffect);
  json += "}";
  server.send(200, "application/json", json);
}

// seťup
void setup() {
  Serial.begin(115200);
  preferences.begin("light-app", false);

  // data
  systemOn = preferences.getBool("sys", true);
  stripOn = preferences.getBool("strip", false);
  ringOn = preferences.getBool("ring", true);
  neoMode = preferences.getInt("nMode", 0);
  neoBrightness = preferences.getInt("nBri", 100);
  stripBrightness = preferences.getInt("sBri", 200);

  pinMode(PIN_SOUND, INPUT);
  pinMode(PIN_BUTTON, INPUT_PULLUP);

  ledcSetup(CH_MOSFET, 5000, 8); ledcAttachPin(PIN_MOSFET, CH_MOSFET);
  ledcSetup(CH_BUZZER, 2000, 8); ledcAttachPin(PIN_BUZZER, CH_BUZZER);
  ledcSetup(CH_R, 5000, 8); ledcAttachPin(RGB_R, CH_R);
  ledcSetup(CH_G, 5000, 8); ledcAttachPin(RGB_G, CH_G);
  ledcSetup(CH_B, 5000, 8); ledcAttachPin(RGB_B, CH_B);

  button.attachClick(btnClick);
  button.attachDoubleClick(btnDouble);
  button.attachMultiClick(btnTriple);
  button.attachLongPressStart(btnLong);
  button.setPressMs(1000);

  ring.begin();
  ring.show();

  WiFi.begin(ST_SSID, ST_PASSWORD);
  int tries = 0;
  while (WiFi.status() != WL_CONNECTED && tries < 20) {
    triggerFeedback(0, 0, 255); // Blink blue
    handleStatusLed(); 
    delay(500);
    hwRGB(0,0,0); delay(100); // Darkness between blinks
    tries++;
  }

  if(WiFi.status() == WL_CONNECTED) {
    triggerFeedback(0, 255, 0); // ok
    beep(2000, 200);
  } else {
    triggerFeedback(255, 0, 0); // error
  }

  server.on("/", handleRoot);
  server.on("/set", handleSet);
  server.on("/status", handleStatus);
  server.begin();
}

// loooooppppp
void loop() {
  server.handleClient();
  button.tick();
  
  handleBeep();
  handleClap();
  handleStrip();
  updateNeo();
  handleStatusLed(); // RGB Function
}

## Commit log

2026-01-19 Circuit diagram
    Added documentation for wiring and components of the Smart Light Control System.
2026-01-19 Circuit diagram
    [ESP32.kicad_sch]
2026-01-19 .STEP Files
    [Holder coupling.step, Holder.step]
2026-01-19 README.md
    Updated clap control and physical button descriptions for clarity.
2026-01-19 Journal.md
    Added detailed journal entries about the ESP32 Smart Light project, including features, how it works, libraries used, and 3D models.
2026-02-01 README.md
    Added a new wiring diagram image to the README.
2026-02-01 Circuit and wiring diagram
